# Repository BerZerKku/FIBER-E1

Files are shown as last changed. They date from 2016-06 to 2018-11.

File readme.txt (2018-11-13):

FIBER-E1
Плата преобразователя ОПТИКА - E1.

01v2

Код ПП: 3.140.968
Код ПП в сборе: 2.141.183

В КЭБ плата идет как повышенной сложности (зазоры на DD1 0.15мм). 
Так же на класс точности влияют переходные отверстия, в КЭБ в данном случае не стали увеличивать диаметр отверстия для VIA.

Ответная часть для разъема аварий (1757268): PHOENIX 175735.

Изменения:
1. Обновлены все элементы из ЦБ.
2. Изменено посадочное место для ПЛИС QFP40P900X900X120-65N_S450V30, было сделано без слоя пасты.
3. На схему добавлены элементы шелкографии (название ПП, дата, логотипы, место маркировки).
4. Переходные отверстия заменены на V800H400.
5. Добавлены реперные точки.

Стэк:
0.018 TOP
0.360
0.035 GND
0.710  
0.035 PWR
0.360 
0.035 BOTTOM

Материал: FR4 (e=4.1, plating thickness=25um))
Финишное покрытие контактных площадок: HAL
Паяльная маска: зеленая.
Есть вырезы на плате.
Отверстия указаны после металлизации.
Платы объеденить в заготовку и согласно рисунку FIBER-E1_01v2_Заготовка.pdf.
В вырез на плате добавить выламываемую заглушку.

Волновое сопротивление (Saturn PCB, e=4.1, plating thickness=25um):
	S60		DP120	
TOP 0,5 	0,25/0,25	
BOT 0,5 	0,25/0,25

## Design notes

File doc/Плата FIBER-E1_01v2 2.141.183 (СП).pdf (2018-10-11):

Напечатано: 05 октября 2018 г. 10:25:44, Щеблыкин Михаил Владимирович
Поз. | Наименование | Корпус | Кол. | Поз. по Э3 | Примечание
| Документация
| Сборочный чертеж 2.141.183 | | 1
| Детали
1 | [3.140.968] Печатная плата FIBER-E1_01v2 | | 1
| Прочее
| Реле
2 | [G6S-2 5VDC] Реле G6S-2 5VDC Omron | DIP-8 | 2 | K1, K2
| Конденсаторы
6 | [0805-X7R-50V-0.1u F-10%] [+]Чип-конденсатор 0805 X7R 50V 0.1uF 10% | 0805 | 25 | C1, C2, C5-C8, C11, C13, C14, C19, C21, C23, C26, C28, C33, C35-C44
7 | [0805-X7R-50V-2.2u F-10%] Чип-конденсатор 0805 X7R 50V 2.2uF 10% | 0805 | 8 | C3, C4, C9, C10, C15, C17, C22, C29
8 | [0805-X7R-10V-10uF -10%] Чип-конденсатор 0805 X7R 10V 10uF 10% | 0805 | 3 | C12, C32, C34
9 | [0805-X7R-50V-0.01 uF-10%] Чип-конденсатор 0805 X7R 50V 0.01uF 10% | 0805 | 2 | C16, C18
10 | [0805-X7R-50V-1uF-10%] [+]Чип-конденсатор 0805 X7R 50V 1uF 10% | 0805 | 1 | C20
11 | [10V-68uF-10%-B] Чип тант. 10V 68uF 10% B | B | 2 | C24, C27

2.141.183

| Лист | № докум | Подп. | Дата
Разраб. | Щеблыкин М.В. | | 01.10.2018 | Плата FIBER-E1_01v2 (Плата FIBER-E1_01v2) | Лит. | Лист | Листов
Провер. | Вершинин А.С. | | 01.10.2018 | | | 1 | 6
Т.контр. | Бокова Т.И. | | 01.10.2018 | | Прософт-Системы
Н.контр. | Назаренко А.Н. | | 01.10.2018
Утв. | Чирков А.Г. | | 01.10.2018

12 | [1812-X7R-3000V-10 00pF-10%] Чип-конденсатор | 1812 | 1 | C25
| 1812 X7R 3000V 1000pF 10%
13 | [10V-220uF-10%-D] Чип тант. 10V 220uF 10% D | D | 2 | C30, C31
| Предохранители,держатели предохранителей
19 | [04611.25ER] Предохранитель 04611.25ER Littelfuse | SMT-2 | 4 | F1-F4
20 | [P6SMB300CA] Диод P6SMB300CA | SMB(DO -214 | 2 | VD2, VD6
21 | [SRDA05-4BTG] Микросхема SRDA05-4BTG SOIC8 LittleFuse | SOIC8 | 1 | VD7
22 | [SM6T6V8A] Диод SM6T6V8A SMB STM | SMB(DO -214 | 1 | VD20
| Дроссели, фильтры, катушки индуктивности
26 | [BLM18HE152SN1] Ферритовый фильтр BLM18HE152SN1 Murata | 0603 | 3 | L1, L2, L4
27 | [PE-65857NL] Фильтр PE-65857NL Pulse | SOIC8 | 1 | L3
28 | [T1094NL] Трансформатор T1094NL Pulse | SOIC16 | 1 | TR1
| Резисторы
32 | [0805-39-5%] Чип-резистор 0805 39 5% | 0805 | 1 | R1
33 | [0805-510-5%] Чип-резистор 0805 510 5% | 0805 | 6 | R2, R7, R10, R23, R24, R26
34 | [0805-10K-5%] Чип-резистор 0805 10K 5% | 0805 | 2 | R3, R4

2.141.183

Лист

2 Изм | Лист | № докум | Подп. | Дата

35 | [0805-5.1-5%] Чип-резистор 0805 5.1 5% | 0805 | 2 | R5, R11
36 | [0805-1K-5%] Чип-резистор 0805 1K 5% | 0805 | 1 | R6
37 | [0805-270-5%] Чип-резистор 0805 270 5% | 0805 | 2 | R8, R12
38 | [0805-5.1K-5%] Чип-резистор 0805 5.1K 5% | 0805 | 2 | R9, R13
39 | [0805-60.4-1%] Чип-резистор 0805 60.4 1% | 0805 | 2 | R14, R15
40 | [0805-3.01K-1%] Чип-резистор 0805 3.01K 1% | 0805 | 1 | R16
41 | [0805-75-5%] Чип-резистор 0805 75 5% | 0805 | 6 | R17-R22
42 | [0805-240-5%] Чип-резистор 0805 240 5% | 0805 | 1 | R25
| Микросхемы
48 | [5M80ZE64C5N] Микросхема 5M80ZE64C5N QFP64 Altera | QFP64 | 1 | DD1
49 | [SN75451BD] Микросхема SN75451BD SOIC8 TI | SOIC8 | 1 | DD2
50 | [HFBR-1414Z] Модуль HFBR-1414Z Avago | DIP-8 | 1 | DD3
51 | [HFBR-2412Z] Модуль HFBR-2412Z Avago | DIP-8 | 1 | DD4
52 | [LP2985AIM5-1.8] Микросхема LP2985AIM5-1.8 SOT23-5 TI | SOT23-5 | 1 | U1
| | | | 3 Изм
Лист | № докум | Подп. | Дата

53 | [82V2081PPG] Микросхема 82V2081PPG LQFP44 IDT | TQFP44 | 1 | U2
54 | [ADP3339AKCZ-3.3] Микросхема ADP3339AKCZ-3.3 SOT223-3 AD | SOT223 | 1 | U3
| Диоды,светодиоды,супрессоры,стабилитроны
58 | [BAT54S] Диод BAT54S SOT23 | SOT23-3 | 2 | VD1, VD5
59 | [L-7104IT] Светодиод L-7104IT Kingbright | LEAD-2 | 2 | VD3, VD4
60 | [P0080SAMCLRP] Тиристор P0080SAMCLRP Littelfuse | DO-214 AA | 2 | VD8, VD10
61 | [P0300SCMCLRP] Тиристор P0300SCMCLRP Littelfuse | DO-214 AA | 2 | VD9, VD11
62 | [P1800SCMCLRP] Тиристор P1800SCMCLRP Littelfuse | DO-214 AA | 4 | VD12-VD15
63 | [MBR0540] Диод MBR0540 SOD123 | SOD123 | 2 | VD16, VD18
64 | [L-7104GC] Светодиод L-7104GC Kingbright | LEAD-2 | 4 | VD17, VD19, VD21, VD22
| Транзисторы
68 | [IRLML6344] Транзистор IRLML6344 MOSFET N-канальный 30V 0.5A SOT23 IR | SOT23-3 | 2 | VT1, VT2
| | | | 4 Изм
Лист | № докум | Подп. | Дата

| Кварцевые генераторы, резонаторы
72 | [SG-8002CA/PCB-65. 536MHz] Кварцевый генератор SG-8002CA/PCB 65.536MHz Epson | SMT-4 | 1 | DD5
| Переключатели, тумблеры
76 | [SWD-08R] Переключатель SWD-08R | DIP16 | 1 | SW1
| Соединители
80 | [IDC-10M] Разъем IDC-10M | IDC10 | 2 | J1, X2
81 | [PLS-40] Разъем PLS-40 | 8 | 12 | X1, J1, J2
82 | [1757268] Ответная часть разъема- MSTBA 2,5/ 4-G-5,08 | 4 | 1 | X3
83 | [1-5406299-1] Разъем 1-5406299-1 на плату угловой Ethernet RJ45 R/A 8P T/H SLD Tyco | 10 | 1 | X4
| | | | 5 Изм
Лист | № докум | Подп. | Дата

Лист регистрации ревизий

№ ревизии | № замененных (измененных) страниц | Дата ревизии | Краткое содержание и причина внесения изменений | Примечание
0 | вновь | 01.10.18

2.141.183

6

Лист Изм. | Лист | № докум. | Подп. | Дата

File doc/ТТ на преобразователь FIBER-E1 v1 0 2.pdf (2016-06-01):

### Технические требования на преобразователь FIBER-E1 Версия документа v1.0.2

Общие сведения
Устройство предназначено для преобразования неструктурированного оптического потока 2.048 Мбит/с в поток E1 G.703 (неструктурированный E1). Оптический интерфейс полностью совместим со спецификацией IEEE C37.94 — устройство может быть использовано как преобразователь IEEE C37.94 — E1 G.703. В составе устройства имеется две нормально замкнутые клеммы («LOS FI» нет оптического сигнала и «LOS E1» нет сигнала E1), сигналы с которых могут быть выведены на внешнюю сигнализацию.
Устройство настраивается с помощью DIP-переключателя.
Оно выполнено в виде самостоятельного модуля и предназначено для крепления на DIN-рейке.

Блоксхема преобразователя FIBER-E1

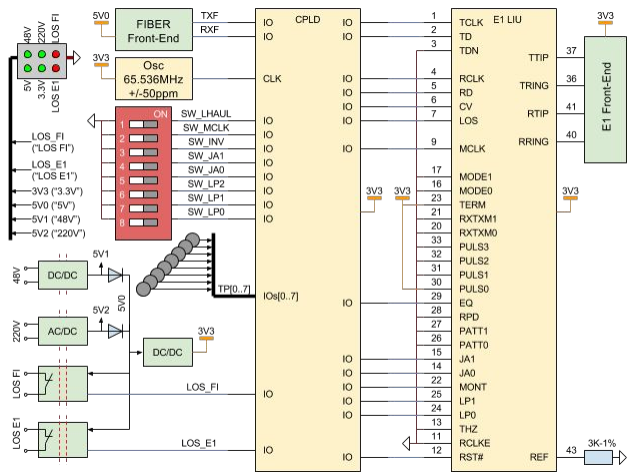
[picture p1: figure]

Механика
Согласовать конструкцию корпуса с конструкторским отделом.
Устройство выполнено в виде самостоятельного модуля и предназначено для крепления на DIN-рейке.

Светодиоды и DIP-переключатель интерфейс пользователя.
Предусмотреть в корпусе отверстия под светодиоды и окно под DIP-переключатель. Предусмотреть место для наклейки с пояснениями для светодиодов и DIP-переключателя.
В установленном положении (на DIN-рейке), состояние светодиодов, DIP-переключателя и надписи на наклейке должны легко считываться.

Электропитание
Устройство должно запитываться от 220В (переменка или постоянка) и 48В (постоянка). Параллельное соединение вторичных напряжений (5В) через схему “активный диод”. Потребляемая мощность по напряжению 3.3В не превышает 0.6Вт.
Потребляемая мощность по напряжению 5В схемой FIBER Front-End не превышает 1Вт. Потребляемая мощность схемой управления 2-мя сигнальными реле (“LOS E1” и “LOS FI”) не должна превышать 0.4Вт.
При использовании схемы “активный диод” и DC/DC преобразователя 5В>3.3В схема гарантированно укладывается в 2Вт потребляемой мощности.
Вместо активных диодов могут быть использованы диоды Шоттки, вместо DC/DC LDO. В таком варианте схема, возможно уже не уложится в 2 Вт потребляемой мощности. Потребуется использовать 3-х ваттные первичные преобразователи.

E1 Front-End
1. Смотри схемотехнику блока БЦК-E1

FIBER Front-End
1. Смотри схемотехнику модуля IEEE_C37_94_Core
2. Заменить DD5 (HFBR-1412TZ)на HFBR-1414Z
3. Заменить DD6 (HFBR-2412TZ) на HFBR-2412Z
4. Заменить R8 (51 Ом) на 39.1 Ом

Тактовый генератор
1. SG-8002CA-PCB-65.536MHz
2. Тактовый сигнал завести на специализированный тактовый порт CPLD

E1 LIU
1. IDT 82V2081PPG
2. соединения информационных и конфигурационных выводов на блоксхеме
3. остальное согласно технической документации на IDT82V2081PPG

CPLD
1. ALTERA 5M80ZE64C5N
2. напряжение питания 3.3В
3. JTAG стандартный ALTERA JTAG, IDC10

4. 8 неиспользуемых портов ввода/вывода использовать в качестве тестовых точек. Вывести их на разъем PLS-8

Светодиоды
1. Светодиоды должны загораться при подаче на них положительного напряжения.
2. Подобрать номиналы резисторов таким образом, чтобы все светодиоды горели с одинаковой интенсивностью
3. Использовать выводные светодиоды диаметром 2.8мм (типа L-934 или подобные).
4. Шаг расстановки светодиодов 5.08мм (в любом направлении).
5. В случае, если светодиоды будут выводиться на боковую (относительно плоскости монтажной платы) панель, то должны быть использованы двухуровневые светодиоды (подобрать варианты http://www.promelec.ru/pdf/L-934DB_2GD.pdf) (http://www.promelec.ru/pdf/L-934DB_2GD.pdf)

Сигнальные реле “LOS FI” и “LOS E1”
1. AXICOM FX2 DC3209, DC3223 (напряжение управляющей катушки 5В) или их аналоги (KEMET EC2, ...)
2. Тип включения нормально замкнутые
3. LOS_FI/LOS_E1 = ‘1’ реле размыкается, LOS_FI/LOS_E1 = ‘0’ реле замыкается

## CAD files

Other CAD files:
doc/Заготовка FIBER-E1_01v2.dwg
order/FIBER-E1_01v2_Заготовка.dwg
pcb/qfp40p900x900x120-65n_s450v30.psm

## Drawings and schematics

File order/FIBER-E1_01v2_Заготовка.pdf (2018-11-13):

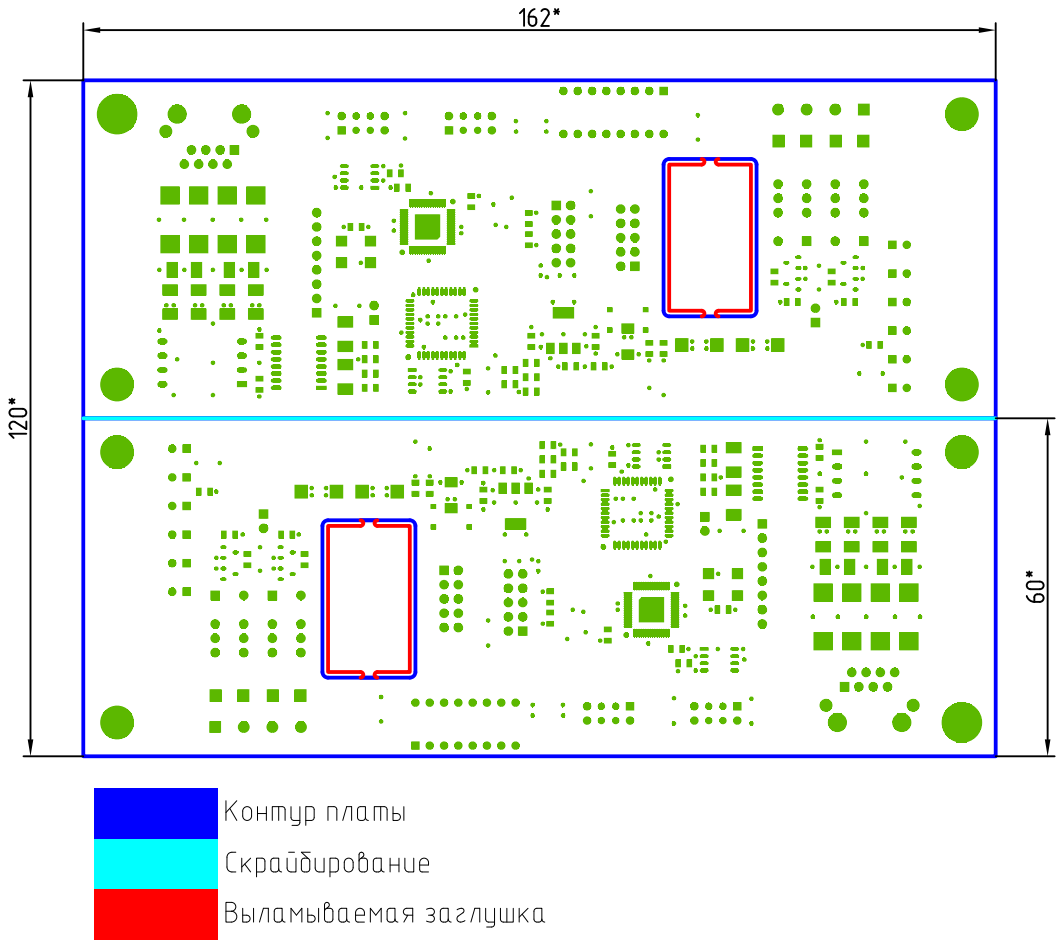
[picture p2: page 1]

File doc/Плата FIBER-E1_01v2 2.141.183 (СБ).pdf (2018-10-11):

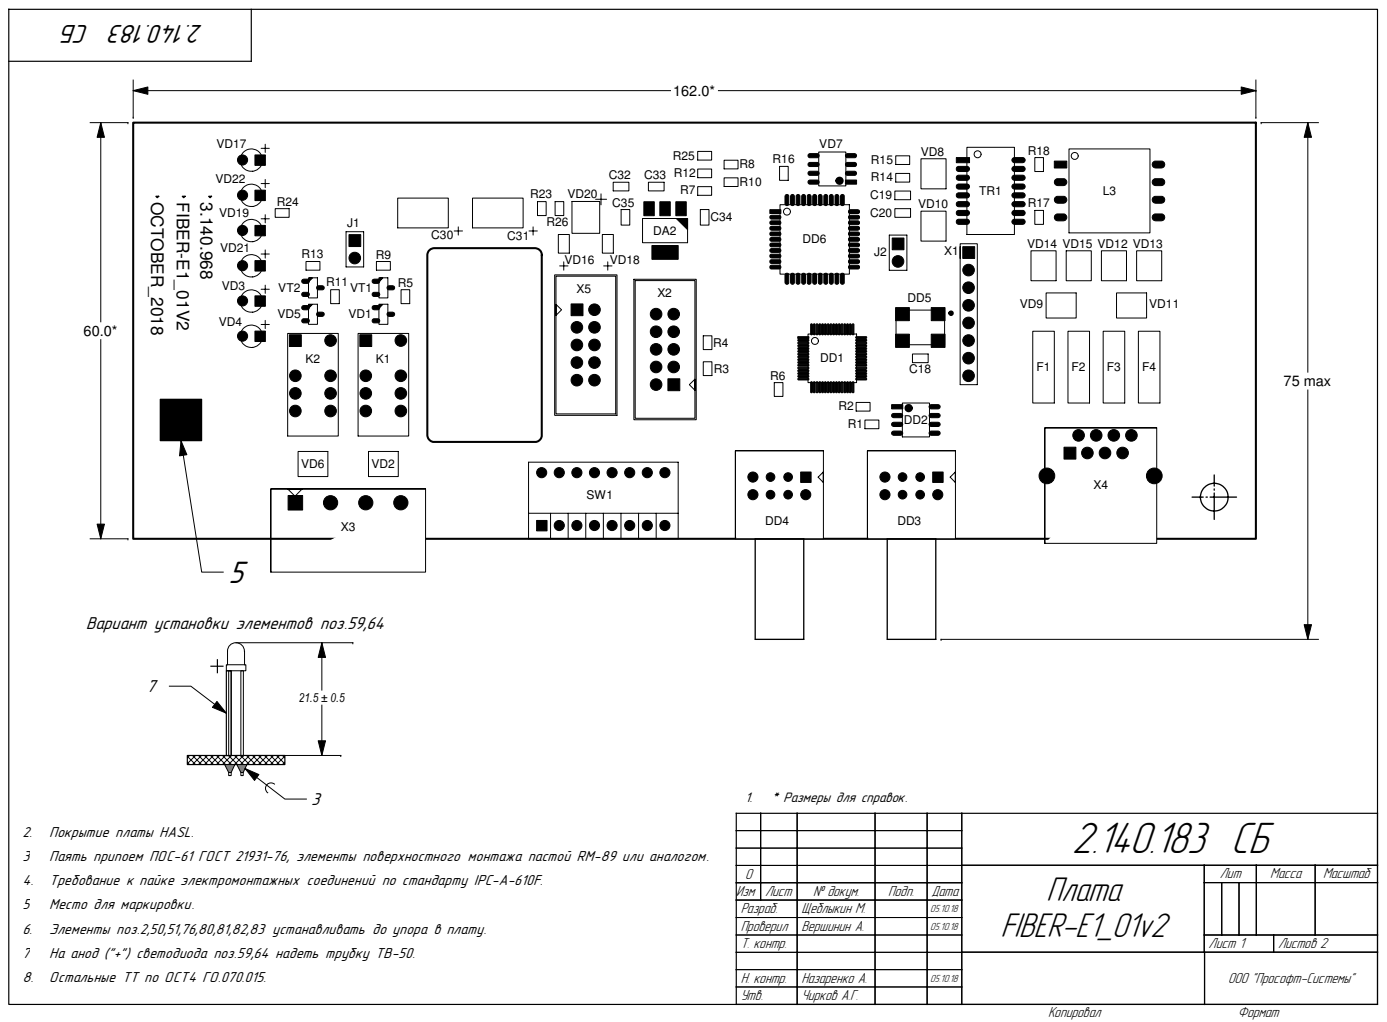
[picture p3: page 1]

Вариант установки элементов поз.59,64

2. Покрытие платы HASL.
3 Паять припоем ПОС-61 ГОСТ 21931-76, элементы поверхностного монтажа пастой RM-89 или аналогом.
4. Требование к пайке электромонтажных соединений по стандарту IPC-A-610F.
5 Место для маркировки.
6. Элементы поз.2,50,51,76,80,81,82,83 устанавливать до упора в плату.
7 На анод ("+") светодиода поз.59,64 надеть трубку ТВ-50.
8. Остальные ТТ по ОСТ4 ГО.070.015.

0 | | | | | Ïëàòà FIBER-E1_01v2 | Ëèò | Ìàññà | Ìàñøòàá
Èçì | Ëèñò | ¹ äîêóì. | Ïîäï. | Äàòà
Ðàçðàá. | | Ùåáëûêèí Ì. | | 05.10.18
Ïðîâåðèë | | Âåðøèíèí À. | | 05.10.18
Ò. êîíòð. | | | | | Ëèñò 1 | Ëèñòîâ 2

Í. êîíòð. | Íàçàðåíêî À. | 05.10.18
Óòâ. | ×èðêîâ À.Ã.

ÎÎÎ "Ïðîñîôò-Ñèñòåìû"

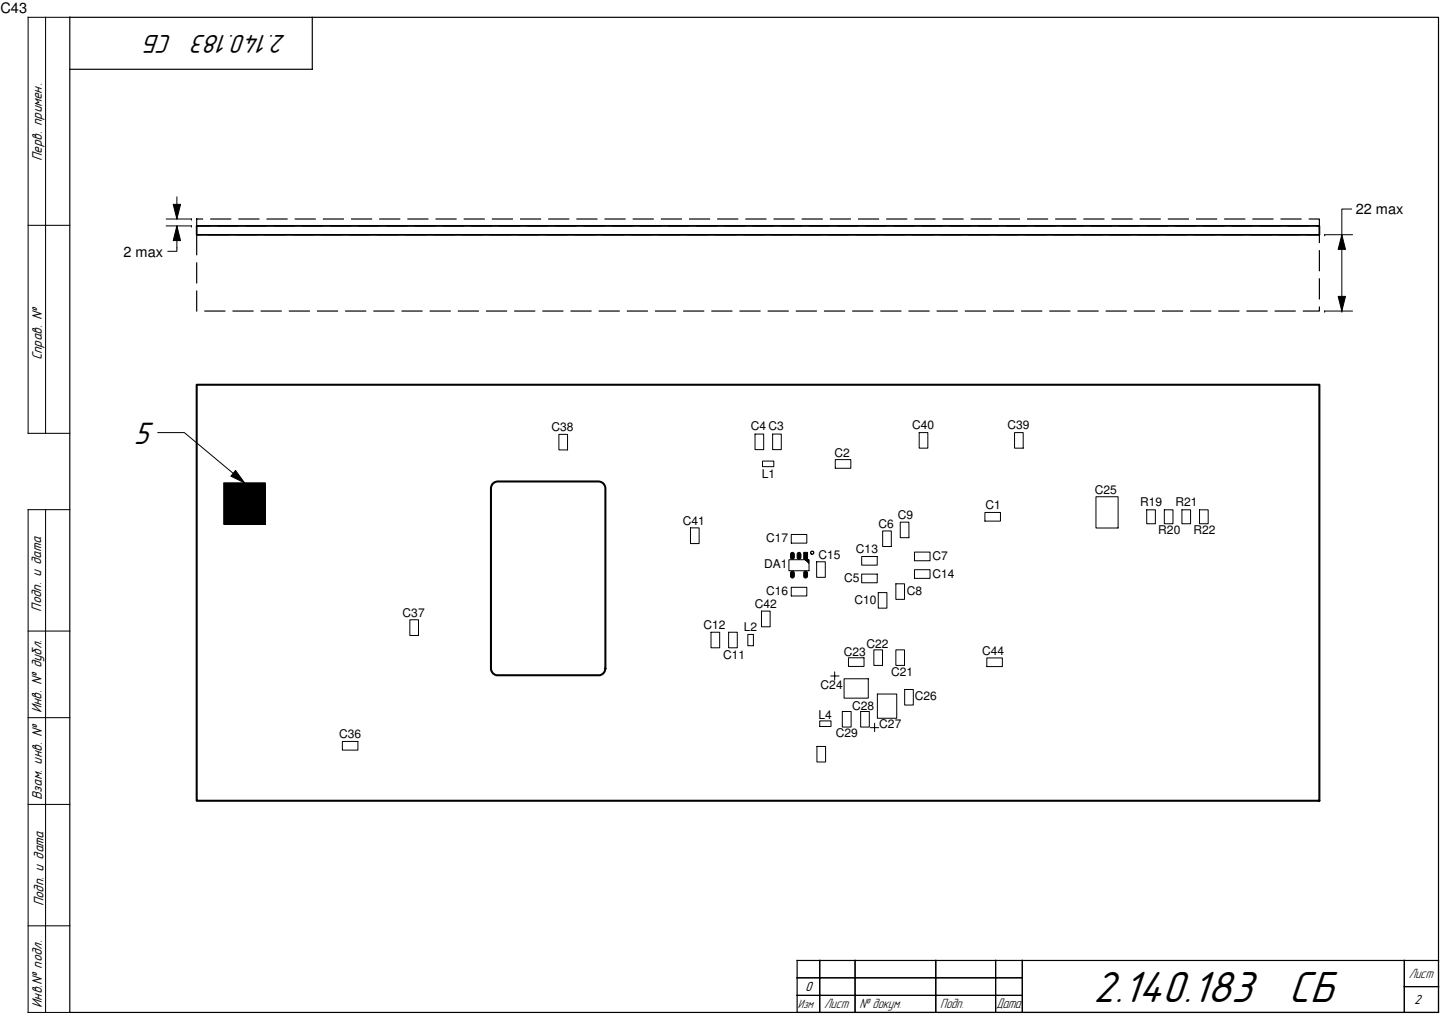
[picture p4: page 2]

Инв.№ подл. Подп. и дата Взам. инв. № Инв. № дубл. Подп. и дата Справ. № Перв. примен. 2 max 22 max C36 C37 C38 C40 C39 C41 C42

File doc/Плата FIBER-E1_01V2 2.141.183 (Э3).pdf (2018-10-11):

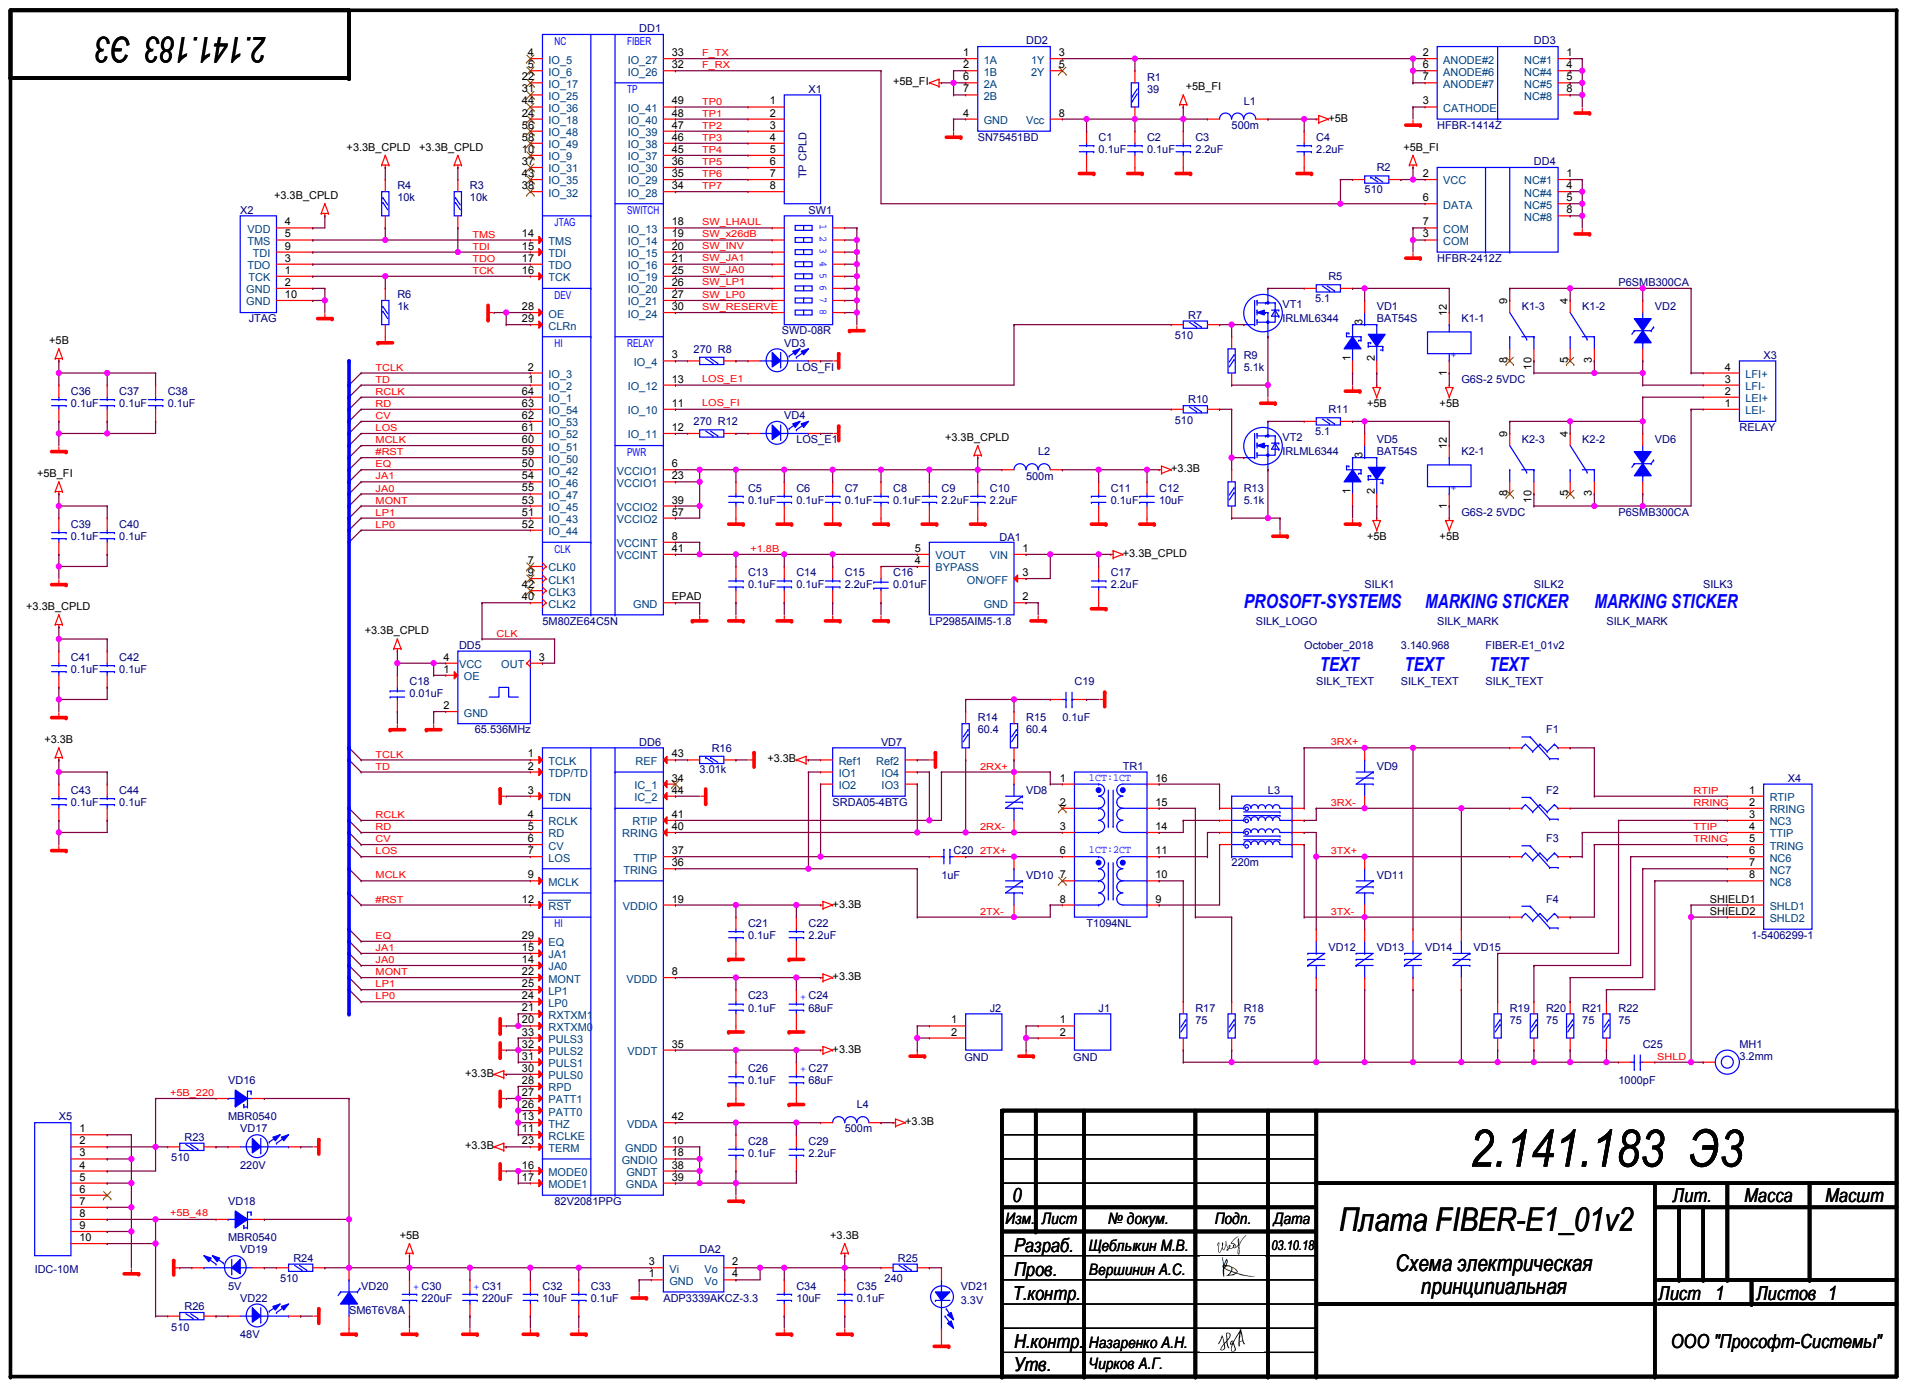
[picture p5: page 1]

0 | | | | | Плата FIBER-E1_01v2 Плата FIBER-E1_01v2 Плата FIBER-E1_01v2 Схема электрическая Схема электрическая Схема электрическая | Лит. | Масса Масса Масса | Масшт Масшт Масшт
Изм. Изм. Изм. | Лист Лист Лист | № докум. № докум. № докум. | Подп. Подп. Подп. | Дата Дата Дата
Разраб. Разраб. Разраб. | | Щеблыкин М.В. Щеблыкин М.В. Щеблыкин М.В. | | 03.10.18 03.10.18 03.10.18
Пров. Пров. Пров. | | Вершинин А.С. Вершинин А.С. Вершинин А.С.
принципиальная Т.контр. принципиальная Т.контр. принципиальная Т.контр. | Лист Лист Лист 1 1 1 1 1 1 | Листов Листов Листов

Н.контр. Н.контр. Н.контр. | Назаренко А.Н. Назаренко А.Н. Назаренко А.Н.
Утв. Утв. Утв. | Чирков А.Г. Чирков А.Г. Чирков А.Г.

ООО "Прософт-Системы" ООО "Прософт-Системы" ООО "Прософт-Системы"

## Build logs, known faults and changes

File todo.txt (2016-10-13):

1. Установить клеммники с возможностью фиксации винтами.

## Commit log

2016-02-01 Вновь.
2016-02-01 Первоначальный вариант схемы. Ножки плис назначены случайным образом.
    [FIBER-E1_01v0.DSN, FIBER-E1_01v0.brd]
2016-02-09 Заменены BLM18HG471SN1 на BLM18HE152SN1.
    [FIBER-E1_01v0.DSN]
2016-02-10 Ведется разводка.
    [FIBER-E1_01v0.DSN, FIBER-E1_01v0.brd]
2016-02-11 Начата перестановка выводов ПЛИС для удобства разводки.
    [FIBER-E1_01v0.DSN, FIBER-E1_01v0.brd]
2016-02-11 Перекидана часть выводов.
    [FIBER-E1_01v0.DSN, FIBER-E1_01v0.brd]
2016-02-11 Начата разводка питания и второстепенных цепей.
    [FIBER-E1_01v0.DSN, FIBER-E1_01v0.brd]
2016-02-11 На плату поставлены светодиоды.
    [FIBER-E1_01v0.DSN, FIBER-E1_01v0.brd]
2016-02-12 Расставлены светодиоды. Начата попытка сдвинуть ПЛИС влево.
    [FIBER-E1_01v0.brd]
2016-02-12 Передвинута ПЛИС.
    [FIBER-E1_01v0.brd]
2016-02-12 Разведены входные цепи Е1. Начата расстановка полигонов питания.
    [FIBER-E1_01v0.brd]
2016-02-12 Прорисовываются полигоны питания.
    [FIBER-E1_01v0.brd]
2016-02-15 Разведено питание.
    [FIBER-E1_01v0.DSN, FIBER-E1_01v0.brd]
2016-02-15 Подправлены полигоны питания.
    [FIBER-E1_01v0.brd]
2016-02-15 Уменьшены габариты платы. Перекинутые пины с платы подтянуты на схему. Добавлены отверстия крепления платы.
    [FIBER-E1_01v0.DSN, FIBER-E1_01v0.brd]
2016-02-15 Расставлены разъемы.
    [FIBER-E1_01v0.brd]
2016-02-15 Сглажены полигоны питания. Немного подвинуты проводники до тестовых точек.
    [FIBER-E1_01v0.brd]
2016-02-15 Сделан отступ в полигоне Route Keepin под разъем Е1. Добавлен исправленный разъем Е1, с габаритами в слое сборки.
    [FIBER-E1_01v0.brd]
2016-02-15 Сделано сглаживание проводников.
    [FIBER-E1_01v0.brd]
2016-02-16 Питание преобразователя 1.8В изменено на 3v3_CPLD. Расставлена шелкография.
    [FIBER-E1_01v0.DSN, FIBER-E1_01v0.brd]
2016-02-16 Изменено посадочное место для ПЛИС, у нее не было соединений с землей. Выполнено filled and tapped trace.
    [FIBER-E1_01v0.brd]
2016-02-16 Мелкие правки шелкографии.
    [FIBER-E1_01v0.brd, qfp40p900x900x120-65n_v2.psm, te_1-5406299-1.psm]
2016-02-17 Ведутся работы по уменьшению габаритов ПП.
    [FIBER-E1_01v0.brd]
2016-02-17 Плата уменьшена с 65 до 60 мм. Перекинута пара цепей на ПЛИС.
    [FIBER-E1_01v0.DSN, FIBER-E1_01v0.brd]
2016-02-17 Подправлена шелкография.
    [FIBER-E1_01v0.DSN, FIBER-E1_01v0.brd]
2016-03-01 Транзисторы заменены на полевые.
    [FIBER-E1_01v0.DSN, FIBER-E1_01v0.brd]
2016-05-06 Передало посадочное место QFP. Переходные отверстия изменены на V800H300.
    [FIBER-E1_01v0.brd, qfp40p900x900x120-65n_v2.psm]
2016-06-01 Добавлена документация на плату.
    [FIBER-E1_01v0.brd]
2016-10-07 1. Исправленоо подклчение разъема X2 JTAG к DD1 (были перепутаны сигнальные линии). 2. Названия цепей на DD1.11 и DD1.13 поменяны друг с другом, чтобы соответствовали надписям на корпусе. 3. Сигналы 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
    Signed-off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
    [FIBER-E1_01v0.DSN, FIBER-E1_01v0.brd, FIBER-E1_01v1.DSN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]
2016-10-11 На плату поставлены символ прософта и области для гравировки. Сделаны проверки и подготовлены герберы.
    [FIBER-E1_01v1.brd]
2016-10-11 Произведена повторная процедура Glossing. Исправлены ошибки.
    [FIBER-E1_01v1.brd]
2016-10-11 Обновлен файл описания.
2016-10-12 Отверстие заземления сделано с переходными отверстиями. Подготовлены файлы заказа.
    [FIBER-E1_01v1 12.10.16.xls, FIBER-E1_01v1.DSN, FIBER-E1_01v1.brd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]
2016-10-13 Сделана документация на плату.
    [FIBER-E1_01v1.brd]
2016-10-13 В СП название документа исправлено на "Плата FIBER-E1_01".
2016-12-06 Добавлены замечания по плате от ЦМПП.
2018-10-03 Элементы схемы синхронизированы с ЦБ. На ПП посадочные места обновлены из ЦБ. Ведется устранение появившихся ошибок.
    [FIBER-E1_01v1.DSN, FIBER-E1_01v1.brd, FIBER-E1_01v2.DSN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]
2018-10-03 Переделано посадочное место для ПЛИС. Добавлены реперные точки и шелкография.
    [FIBER-E1_01v2.DSN, FIBER-E1_01v2.brd, qfp40p900x900x120-65n_s450v30.psm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]
2018-10-11 Добавлена документация.
    [FIBER-E1_01v2.DSN, FIBER-E1_01v2.brd, FIBER-E1_01v2_Заготовка.dwg]
2018-11-13 В файл проекта ПП добавлены слои пасты. На заготовке добавлено выламываемое отверстие. Добавлены файлы заказа.
    [FIBER-E1_01v1 12.10.16.xls, FIBER-E1_01v2 12.11.18.xls, FIBER-E1_01v2.brd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]
2018-11-30 Добавлен CAM файл заготовки.
    [FIBER-E1_01v2 12.11.18.xls, FIBER-E1_01v2 16.11.18.xls]
